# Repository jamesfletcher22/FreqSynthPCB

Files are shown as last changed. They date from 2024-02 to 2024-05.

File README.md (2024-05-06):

# FreqSynthPCB
A PCB Design for an Si5351A Frequency Synthesiser with Manual Control

This is a PCB I designed for a Si5351a Frequency Synthesiser. It can generate a clock at any arbitrary frequency with 1KHz resolution up to 125MHz.
Control is done using a ATMEGA328-PB. 
There is a rotary encoder to control the frequency at the output, along with an OLED for displaying the selected frequency





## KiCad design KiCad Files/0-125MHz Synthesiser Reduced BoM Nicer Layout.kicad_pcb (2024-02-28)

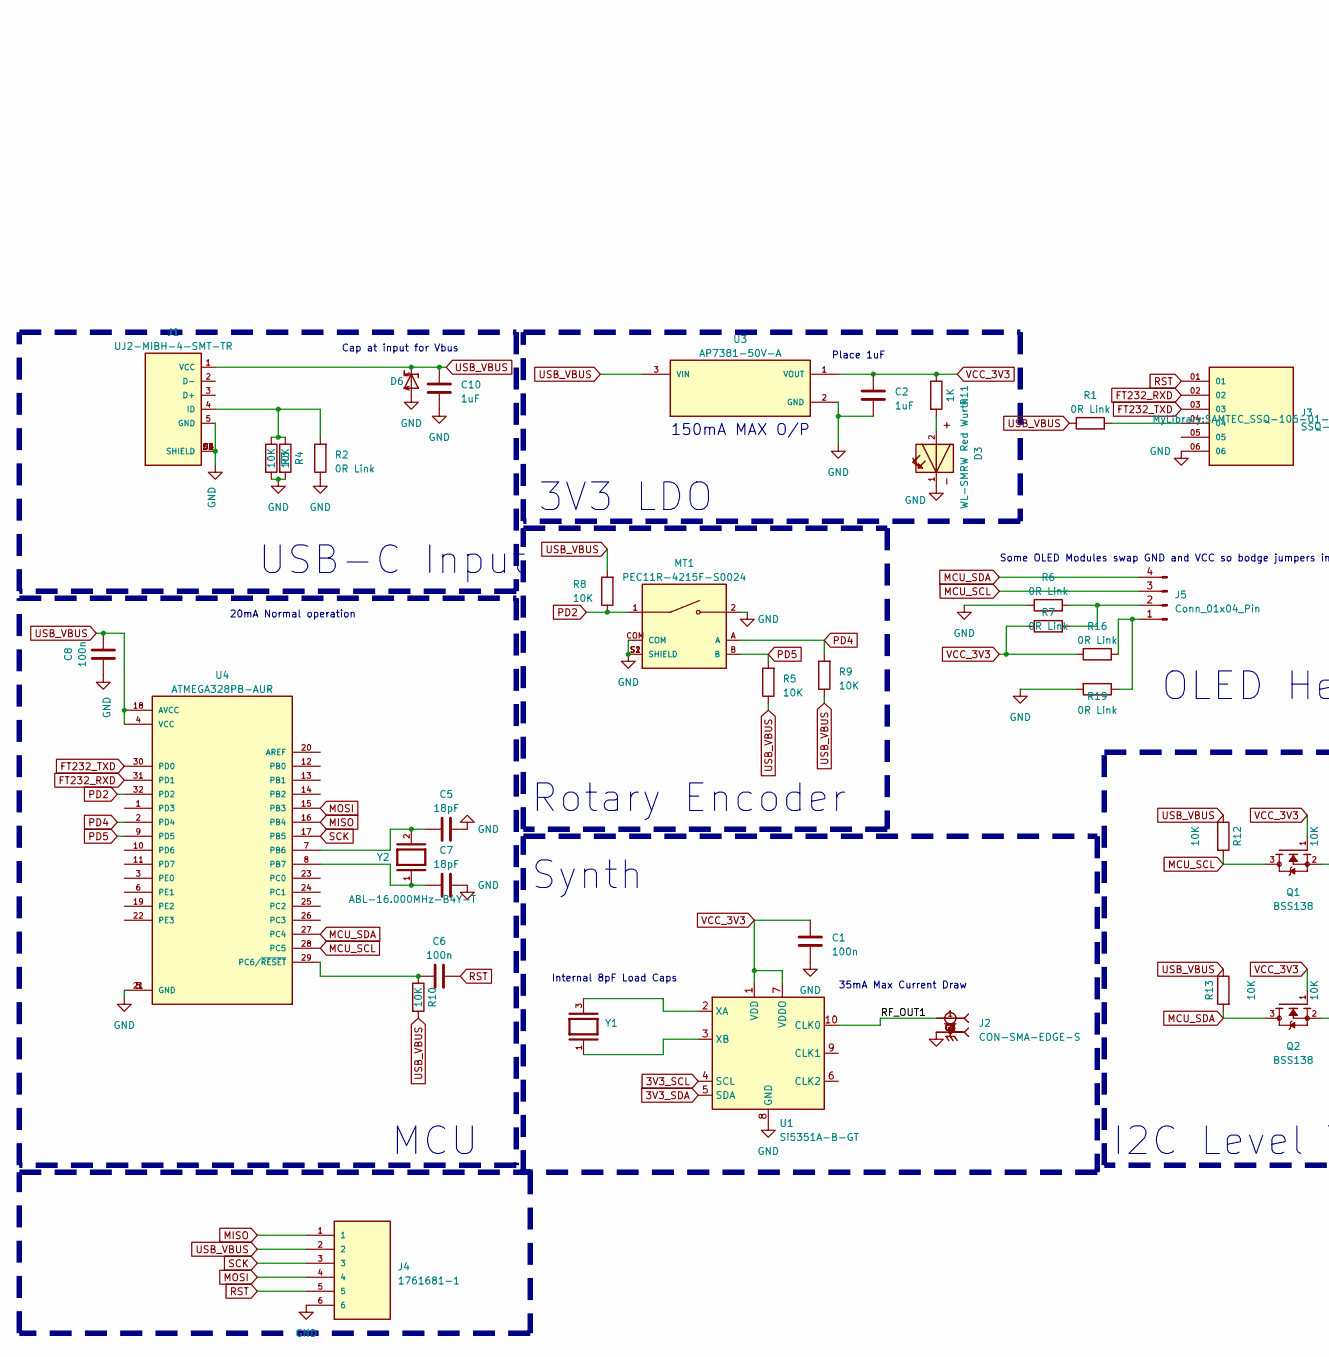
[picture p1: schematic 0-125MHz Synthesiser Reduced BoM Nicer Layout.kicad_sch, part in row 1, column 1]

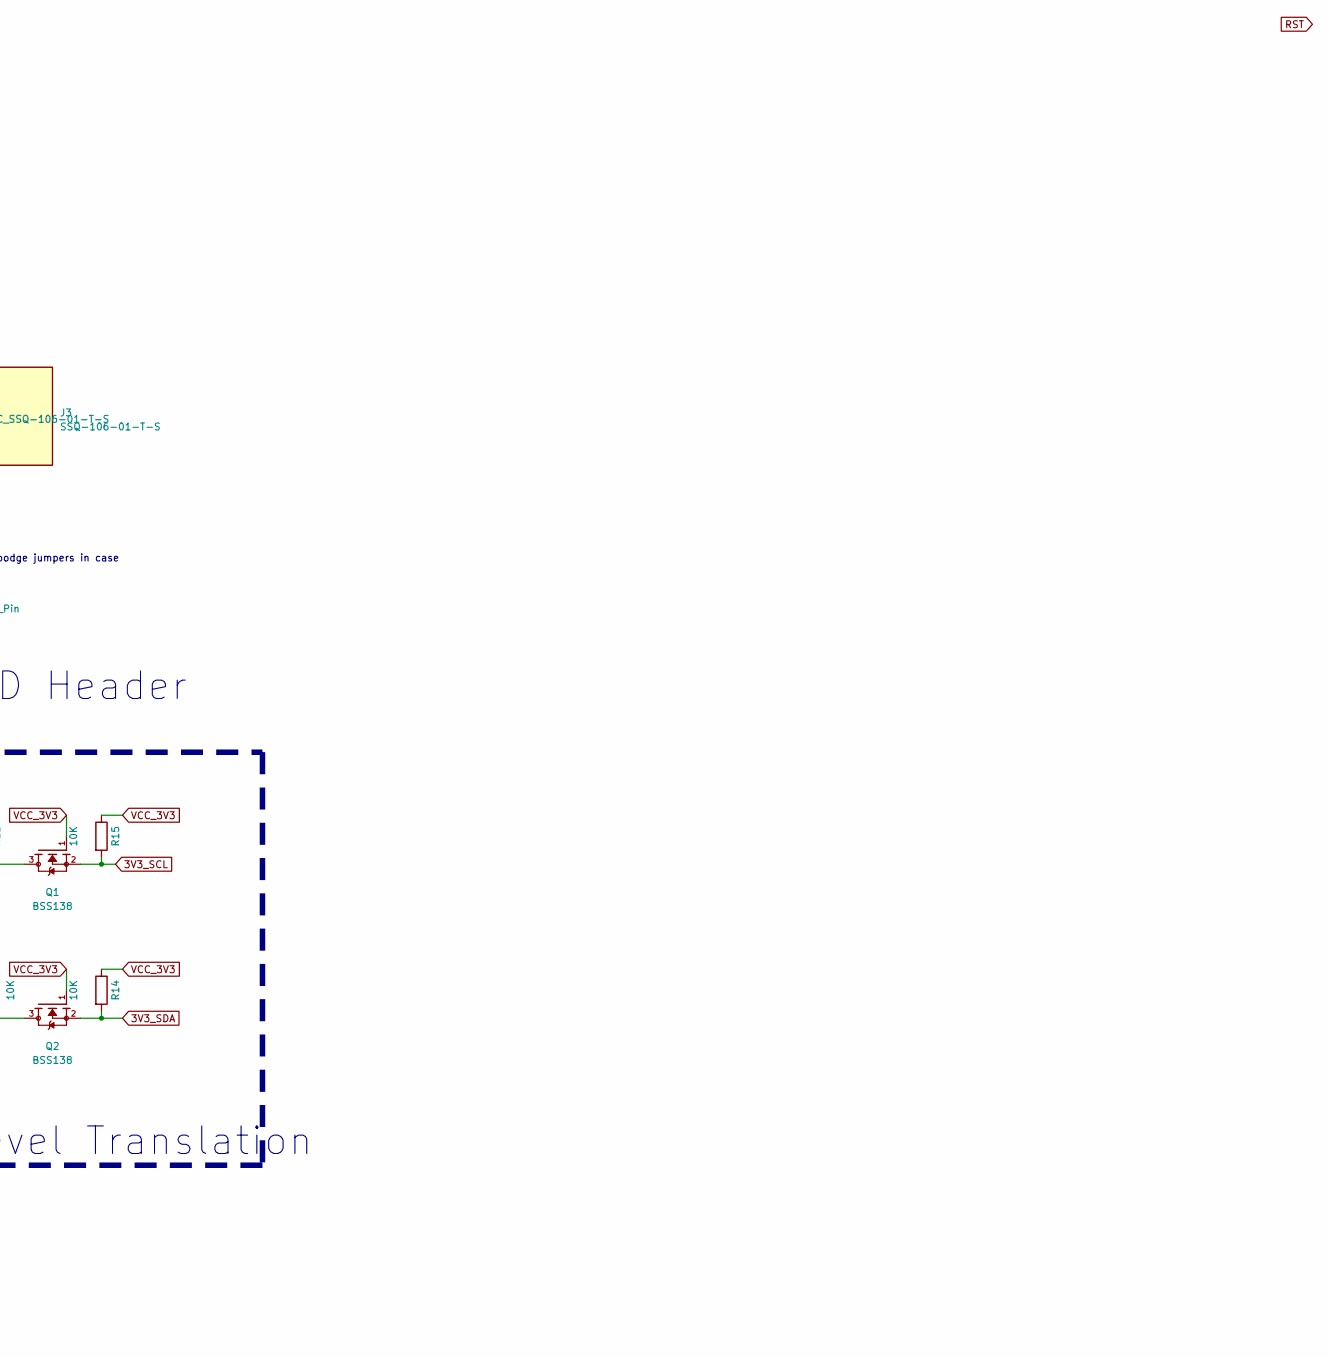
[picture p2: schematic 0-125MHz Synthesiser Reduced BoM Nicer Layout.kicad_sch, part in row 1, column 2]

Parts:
C1, C6, C8: 100n; C_1206_3216Metric_Pad1.33x1.80mm_HandSolder
C2, C10: 1uF; C_1206_3216Metric_Pad1.33x1.80mm_HandSolder
C5, C7: 18pF; C_1206_3216Metric_Pad1.33x1.80mm_HandSolder
D3: WL-SMRW Red Wurth; WL-SMRW-1206-RECT
D6: ESD5Z6.0T1G; SOD-523
J1: UJ2-MIBH-4-SMT-TR; CUIDEVICES_UJ2-MIBH-4-SMT-TR; PARTREV 1.01
J2: CON-SMA-EDGE-S; RFSOLUTIONS_CON-SMA-EDGE-S; PARTREV 1
J3: SSQ-106-01-T-S; SAMTEC_SSQ-106-01-T-S; PARTREV R
J4: 1761681-1; PinHeader_2x03_P2.54mm_Vertical; PARTREV R
J5: Conn_01x04_Pin; PinHeader_1x04_P2.54mm_Vertical
MT1: PEC11R-4215F-S0024; XDCR_PEC11R-4215F-S0024; PARTREV Rev. 09/19
Q1, Q2: BSS138; SOT95P240X111-3N
R1, R2, R6, R7, R16, R19: 0R Link; SolderJumper-2_P1.3mm_Open_RoundedPad1.0x1.5mm
R3, R4, R5, R8, R9, R10, R12, R13, R14, R15: 10K; R_1206_3216Metric_Pad1.30x1.75mm_HandSolder
R11: 1K; R_1206_3216Metric_Pad1.30x1.75mm_HandSolder
U1: Si5351A-B-GT; MSOP-10_3x3mm_P0.5mm
U3: AP7381-50V-A; TO92254P480H8703; PARTREV 3 - 2
U4: ATMEGA328PB-AUR; QFP80P900X900X120-32N; PARTREV NA
Y1: XRCGB25M000F2P00R0; OSC_XRCGB25M000F2P00R0; PARTREV N/A
Y2: ABL-16.000MHz-B4Y-T; XTAL_HC49P488W46L1150T500H350; PARTREV 03.27.2018

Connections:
3V3_SCL: Q1.2, R15.2, U1.4 (SCL)
3V3_SDA: Q2.2, R14.2, U1.5 (SDA)
/RF_OUT1: J2.1, U1.10 (CLK0)
FT232_RXD: J3.02, U4.31 (PD1)
FT232_TXD: J3.03, U4.30 (PD0)
GND: C1.1, C2.2, C5.1, C7.1, C8.2, C10.2, D3.1, D6.A, J1.5 (GND), J1.P5 (SHIELD), J1.P6 (SHIELD), J1.S1 (SHIELD), J1.S2 (SHIELD), J1.S3 (SHIELD), J1.S4 (SHIELD), J2.G1, J2.G2, J2.G3, J2.G4, J3.06, J4.6, MT1.2, MT1.COM, MT1.S1 (SHIELD), MT1.S2 (SHIELD), R2.1, R3.2, R4.2, R6.1, R19.2, U1.8 (GND), U3.2 (GND), U4.5 (GND), U4.21 (GND)
MCU_SCL: J5.3, Q1.3, R12.2, U4.28 (PC5)
MCU_SDA: J5.4, Q2.3, R13.2, U4.27 (PC4)
MISO: J4.1, U4.16 (PB4)
MOSI: J4.4, U4.15 (PB3)
unnamed: D3.2, R11.2
unnamed: J1.4 (ID), R2.2, R3.1, R4.1
unnamed: J3.04, R1.2
unnamed: J5.1, R16.2, R19.1
unnamed: J5.2, R6.2, R7.2
unnamed: U1.2 (XA), Y1.3
unnamed: U1.3 (XB), Y1.1
unnamed: C5.2, U4.7 (PB6), Y2.2
unnamed: C7.2, U4.8 (PB7), Y2.1
unnamed: C6.1, R10.1, U4.29 (PC6/~RESET)
PD2: MT1.1, R8.1, U4.32 (PD2)
PD4: MT1.A, R9.2, U4.2 (PD4)
PD5: MT1.B, R5.2, U4.9 (PD5)
RST: C6.2, J3.01, J4.5
SCK: J4.3, U4.17 (PB5)
USB_VBUS: C8.1, C10.1, D6.K, J1.1 (VCC), J4.2, R1.1, R5.1, R8.2, R9.1, R10.2, R12.1, R13.1, U3.3 (VIN), U4.4 (VCC), U4.18 (AVCC)
VCC_3V3: C1.2, C2.1, Q1.1, Q2.1, R7.1, R11.1, R14.1, R15.1, R16.1, U1.1 (VDD), U1.7 (VDDO), U3.1 (VOUT)

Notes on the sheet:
MCU
OLED Header
I2C Level Translation
Some OLED Modules swap GND and VCC so bodge jumpers in case
3V3 LDO
150mA MAX O/P
20mA Normal operation
35mA Max Current Draw
Internal 8pF Load Caps
USB-C Input
Cap at input for Vbus
Synth
Rotary Encoder
Place 1uF

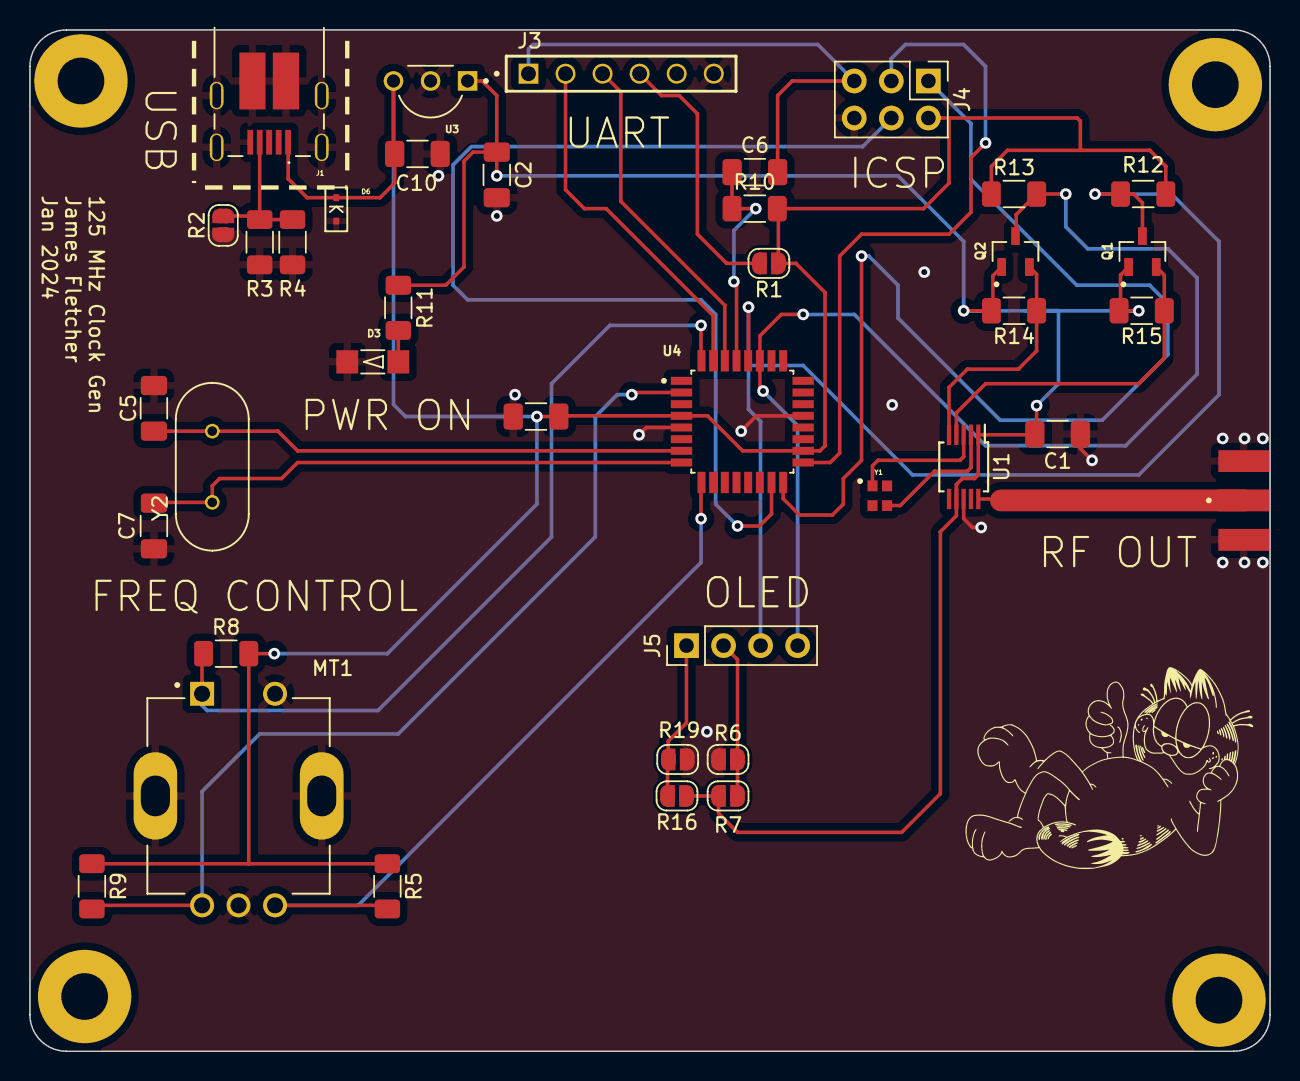
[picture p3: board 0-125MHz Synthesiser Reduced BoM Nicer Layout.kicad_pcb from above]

Board: 2 copper layers, 85.0 x 70.0 mm, 39 parts (0 on the bottom side), 27 nets.
